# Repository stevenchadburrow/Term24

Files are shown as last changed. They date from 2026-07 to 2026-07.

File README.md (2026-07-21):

# Term24
VGA Terminal/Graphics Module using a PIC24<br>

This module is designed to output an 80x24 Terminal to a VGA display.  It accepts standard ANSI escape codes and includes customized escape codes for switching modes and changing internal memory.  It also has the capability of displaying 128x128 pixels at 128 colors, either double-buffered, layered, or with scrolling.  It has built in buttons to double as a gamepad.<br>

It can be accessed through four different protocols: UART, PS/2 Keyboard, SPI, or Parallel Input.  It can be used as a shield for the Arduino Uno, or it can be used with any homebrew computer and is easily plugged in to a breadboard.  It also has 'Tetra' as a built-in game!<br>

It uses the PIC24EP512GP202 microcontroller, running at 65 MIPS and containing 512KB of ROM and 48KB of RAM.  The only other IC on-board is the LM1117 voltage regulator.  All components are through-hole for ease of soldering.<br>

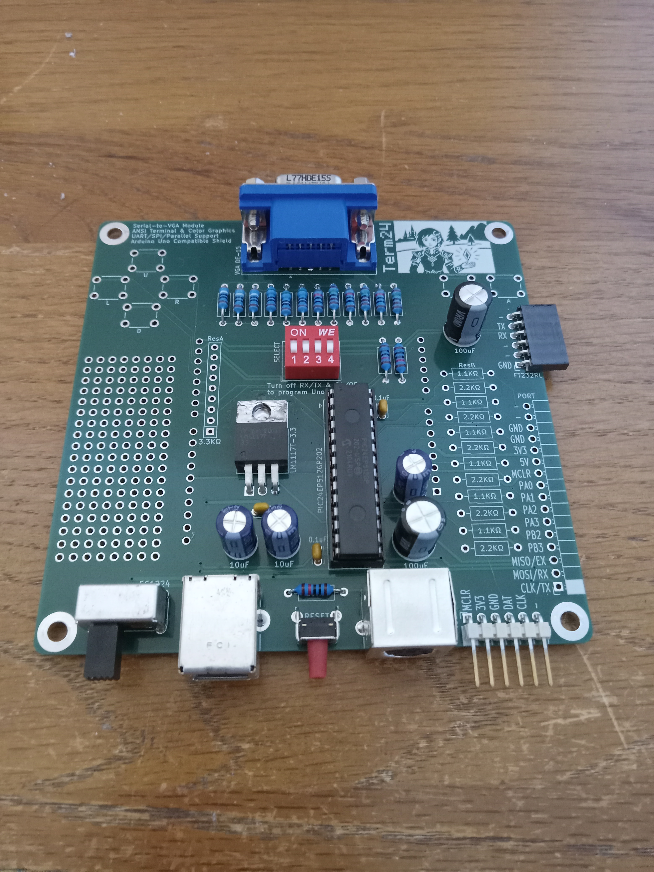
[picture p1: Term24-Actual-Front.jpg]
<br>
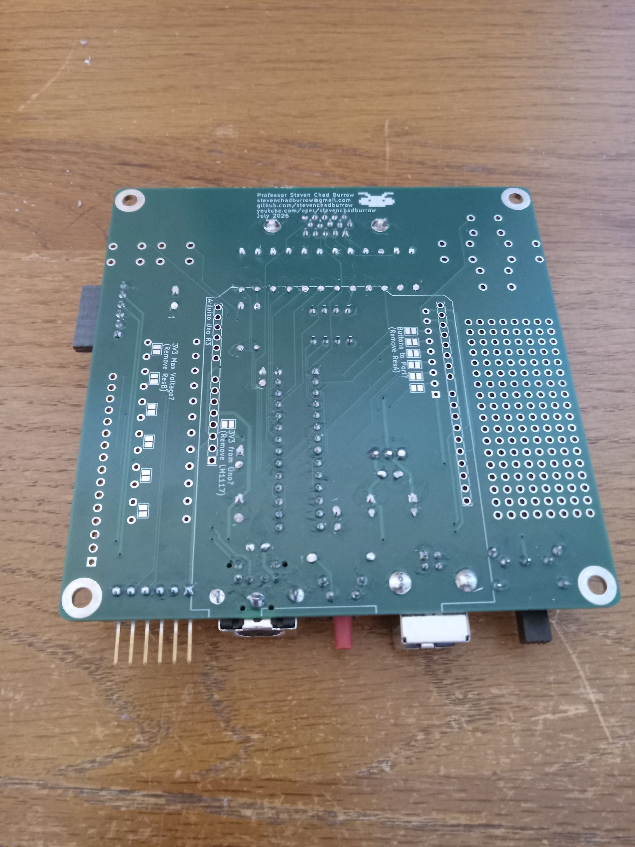
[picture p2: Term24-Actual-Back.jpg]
<br>
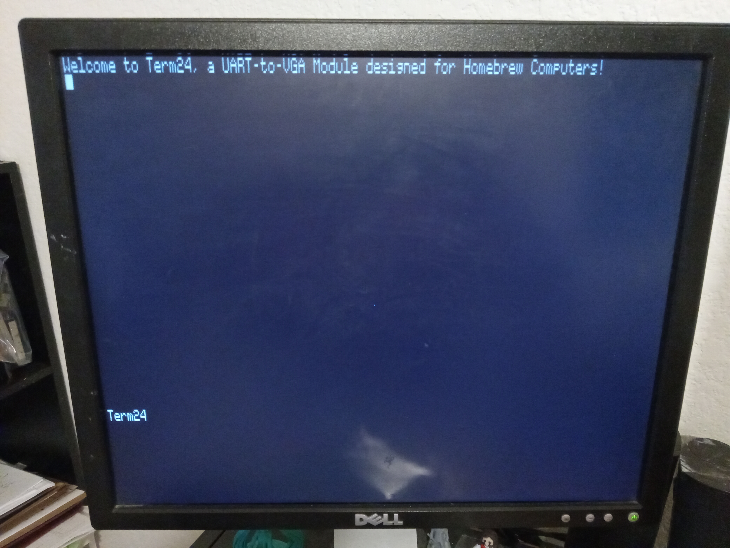
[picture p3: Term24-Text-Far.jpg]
<br>
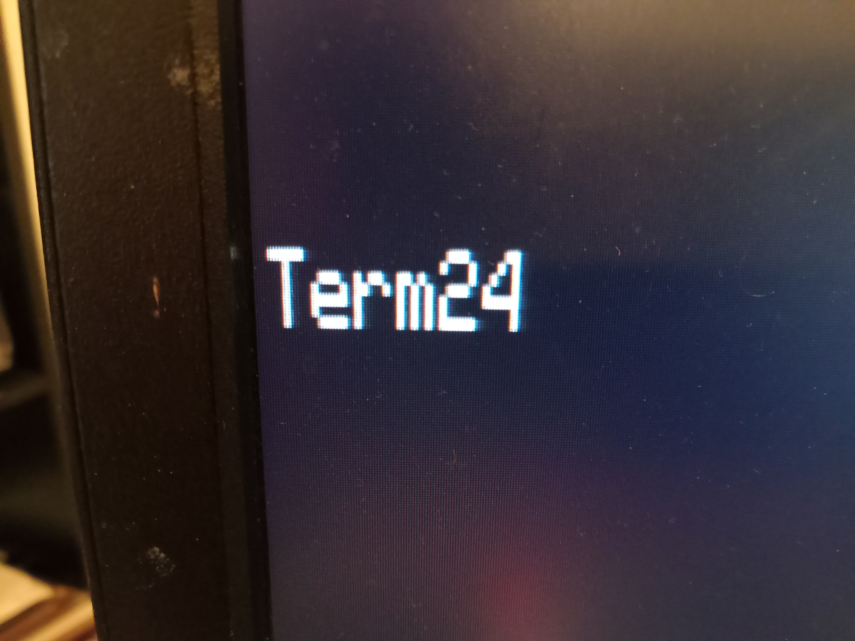
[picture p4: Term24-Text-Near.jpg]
<br>
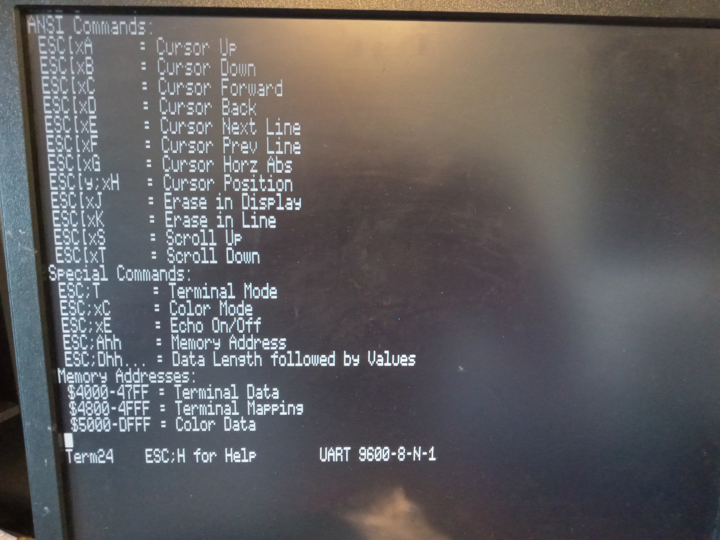
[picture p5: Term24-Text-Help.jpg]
<br>
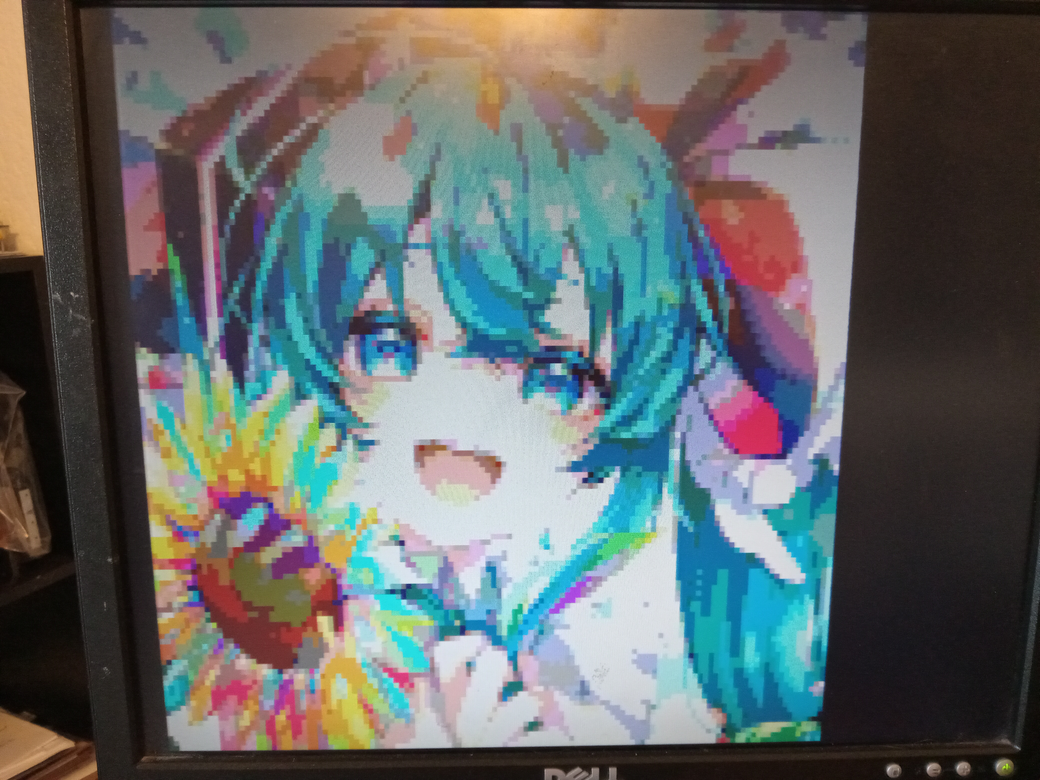
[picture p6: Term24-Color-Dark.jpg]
<br>
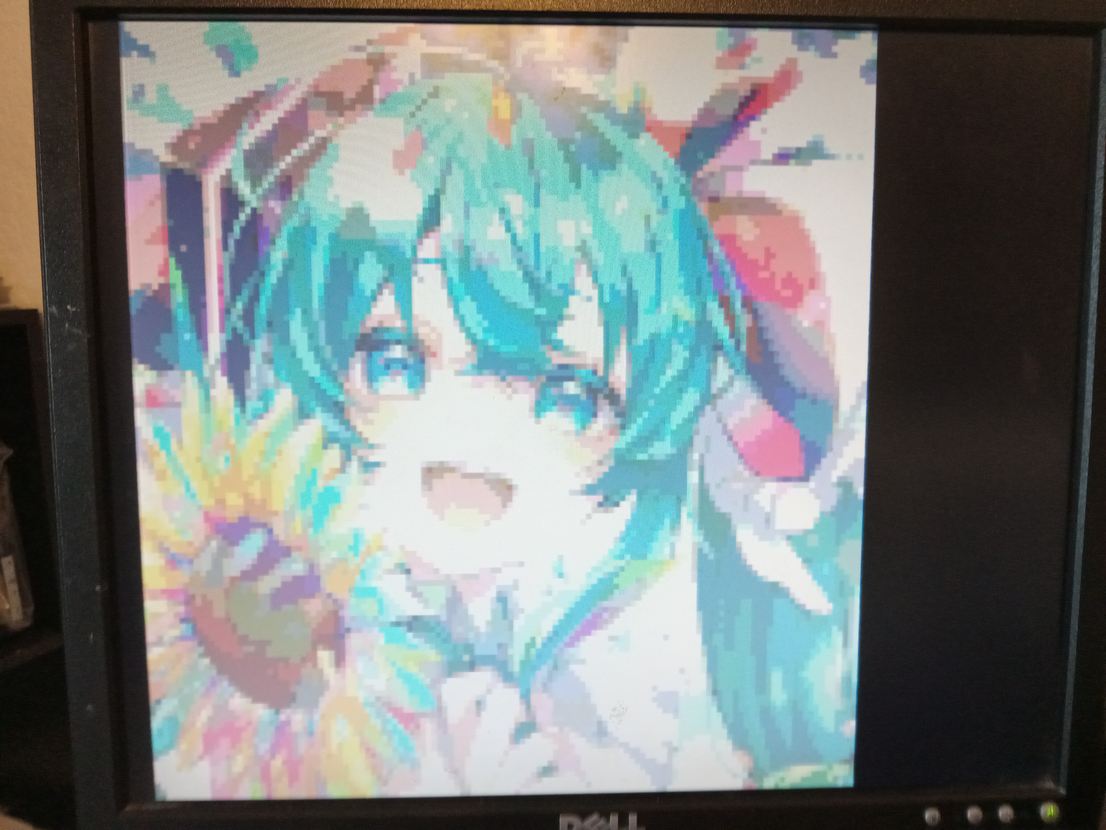
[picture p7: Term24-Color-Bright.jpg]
<br>
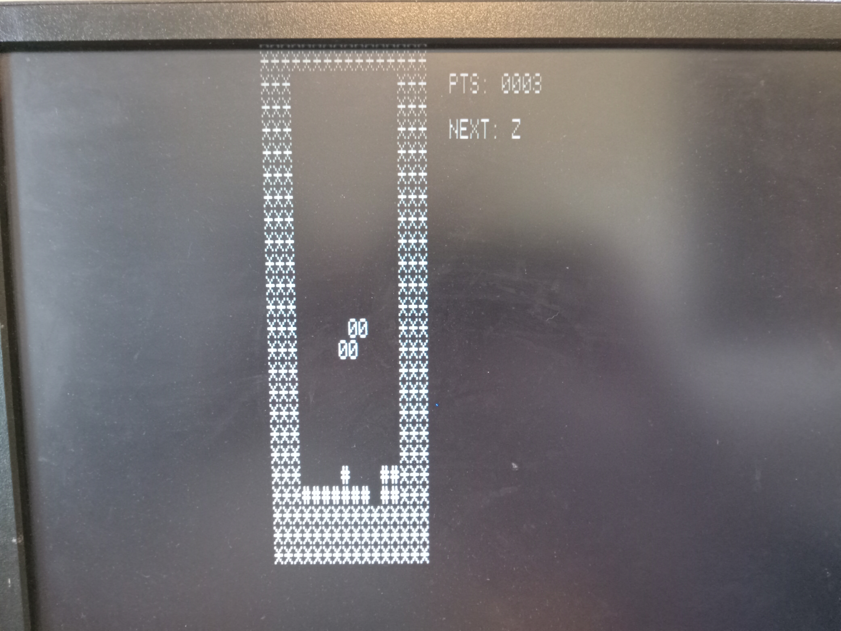
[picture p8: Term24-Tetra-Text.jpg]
<br>
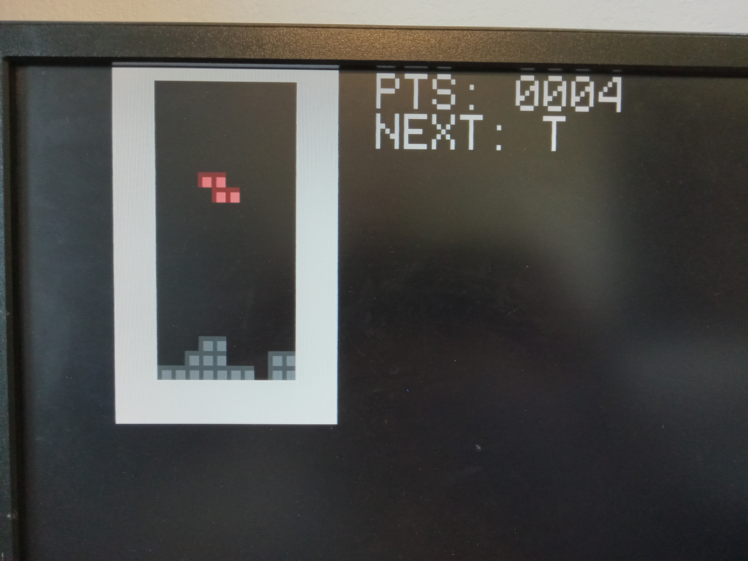
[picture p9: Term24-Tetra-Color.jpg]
<br>
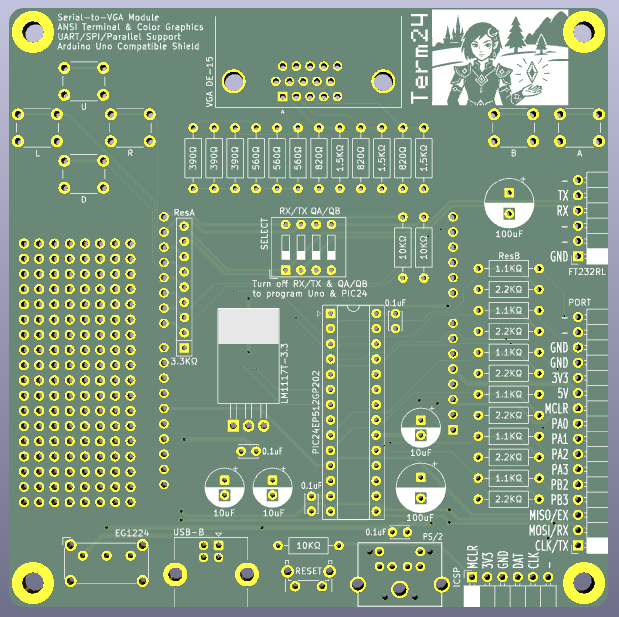
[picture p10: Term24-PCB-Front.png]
<br>
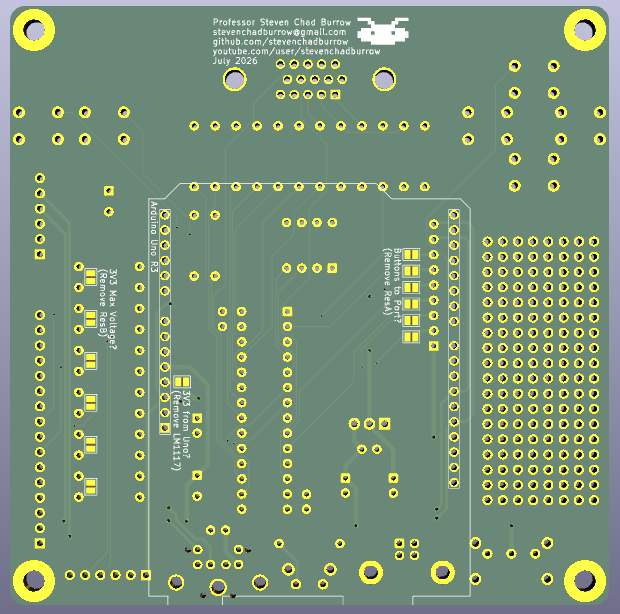
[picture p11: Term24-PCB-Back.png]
<br>

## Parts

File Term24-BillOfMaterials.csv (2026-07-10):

Quantity | Part ID | Description
1 | PIC24EP512GP202-I/SP | PIC24 Microcontroller
1 | 1-2199298-9 | DIP-28 Socket
1 | LM1117T-3.3/NOPB | LDO Voltage Regulator (3V3)
1 | L77HDE15SD1CH4FVGA | VGA Connector DE-15
1 | EG1224 | Power Switch
1 | 61729-1011RLF | USB-B Receptacle
1 | KMDGX-6S-BS | PS/2 Keyboard Connector
1 | SSQ-106-02-T-S-RA | 6-Pin Socket Horizontal
1 | TSW-116-25-L-S-RA | 6-Pin Header Horizontal
1 | TSW-116-25-L-S-RA | 16-Pin Header Horizontal
3 | 42375-1866 | 13-Pin Header Vertical (Breakway)
1 | PTS645VK83-2 LFS | Tactile Switch (Right Angle, 8.3mm)
6 | TS02-66-130-BK-160-SCR-D | Tactile Switch (6x6x13mm)
1 | 418117270904 | 4x DIP Switch
1 | 4609X-101-332LF | 8x Resistor Array 3.3K ohms
3 | ESK106M100AE3EA | 10uF Capacitor Electrolytic Radial
2 | UVR1H101MPD | 100uF Capacitor Electrolytic Radial
4 | K104K15X7RF5UL2 | 0.1uF Capacitor Ceramic MLCC
3 | MFR-25FRF52-10K | 10K ohm resistor 1/4W 1%
6 | MFR-25FRF52-1K1 | 1.1K ohm resistor 1/4W 1%
6 | MFR-25FRF52-2K2 | 2.2K ohm resistor 1/4W 1%
3 | MFR-25FTF52-390R | 390 ohm resistor 1/4W 1%
3 | MFR-25FTF52-560R | 560 ohm resistor 1/4W 1%
3 | MFR-25FBF52-820R | 820 ohm resistor 1/4W 1%
3 | MFR-25FTF52-1K5 | 1.5K ohm resistor 1/4W 1%

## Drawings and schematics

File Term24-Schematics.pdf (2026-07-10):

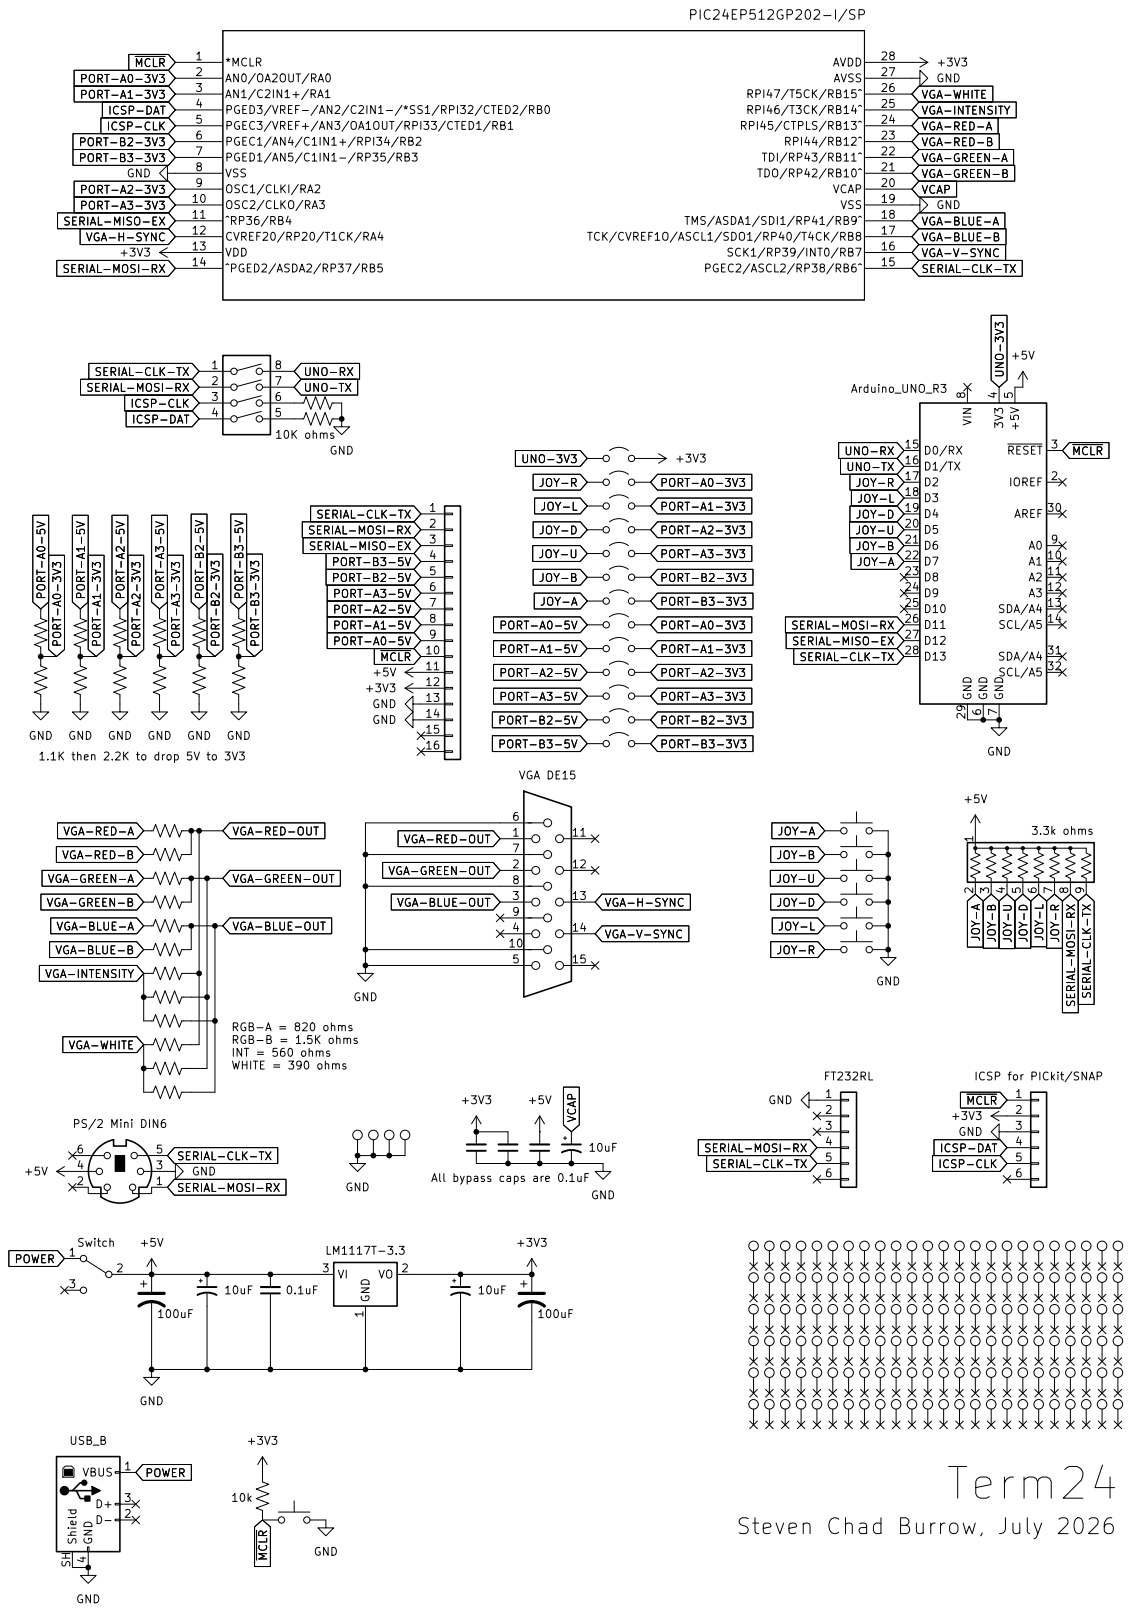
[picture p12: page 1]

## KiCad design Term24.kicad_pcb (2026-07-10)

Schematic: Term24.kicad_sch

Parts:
A1: Arduino_UNO_R3; Arduino_UNO_R3-Revised
C1, C6, C8: C_Polarized_Small_US; CP_Radial_D6.3mm_P2.50mm
C2, C3: C_Polarized_US; CP_Radial_D8.0mm_P3.50mm
C5, C19, C25, C26: C_Small; C_Disc_D3.0mm_W2.0mm_P2.50mm
J1: USB_B; USB_B_Lumberg_2411_02_Horizontal
J2: Conn_01x16; PinSocket_1x16_P2.54mm_Horizontal
J5: Mini-DIN-6; PS2_Din6
J11: VGA DE15; DSUB-15-HD_Socket_Horizontal_P2.29x2.54mm_EdgePinOffset8.35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
J14, J15: Conn_01x06; PinSocket_1x06_P2.54mm_Horizontal
JP1, JP2, JP3, JP4, JP5, JP6, JP7, JP8, JP9, JP10, JP11, JP12, JP13: Jumper_2_Open; SolderJumper-2_P1.3mm_Open_Pad1.0x1.5mm
R2, R9, R14, R16, R17, R18, R19, R20, R28, R29, R30, R31, R32, R33, R34, R35, R36, R37, R38, R39, R40, R41, R42, R43, R44, R45, R46: R_US; R_Axial_DIN0207_L6.3mm_D2.5mm_P10.16mm_Horizontal
RN1: R_Network08_US; R_Array_SIP9
SW3: SW_SPDT; SW_E-Switch_EG1224_SPDT_Angled
SW4, SW5, SW6, SW7, SW8, SW9: SW_Push; SW_PUSH_6mm_H7.3mm
SW10: SW_DIP_x04; SW_DIP_SPSTx04_Slide_9.78x12.34mm_W7.62mm_P2.54mm
SW11: SW_Push; SW_Tactile_SPST_Angled_PTS645Vx83-2LFS
TP1, TP6, TP7, TP8, TP9, TP10, TP11, TP12, TP13, TP14, TP15, TP16, TP17, TP18, TP19, TP20, TP21, TP22, TP23, TP24, TP25, TP26, TP27, TP28, TP29, TP30, TP31, TP32, TP33, TP34, TP35, TP36, TP37, TP38, TP39, TP40, TP41, TP42, TP43, TP44, TP45, TP46, TP47, TP48, TP49, TP50, TP51, TP52, TP53, TP54, TP55, TP56, TP57, TP58, TP59, TP60, TP61, TP62, TP63, TP64, TP65, TP66, TP67, TP68, TP69, TP70, TP71, TP72, TP73, TP74, TP75, TP76, TP77, TP78, TP79, TP80, TP81, TP82, TP83, TP84, TP85, TP86, TP87, TP88, TP89, TP90, TP91, TP92, TP93, TP94, TP95, TP96, TP97, TP98, TP99, TP100, TP101, TP102, TP103, TP104, TP105, TP106, TP107, TP108, TP109, TP110, TP111, TP112, TP113, TP114, TP115, TP116, TP117, TP118, TP119, TP120, TP121, TP122, TP123, TP124, TP125, TP126, TP127, TP128, TP129, TP130, TP131, TP132, TP133, TP134, TP135, TP136, TP137, TP138, TP139, TP140, TP141, TP142, TP143, TP144, TP145, TP146, TP147, TP148: TestPoint; PinHeader_1x01_P2.54mm_Vertical_TestPoint
TP2, TP3, TP4, TP5: TestPoint; ScrewHole-4-40
U1: PIC24EP512GP202-I/SP; DIP-28_W7.62mm_Socket
U5: LM1117T-3.3; TO-223-3-WithPad

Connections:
+3V3: C3.1, C6.1, C19.2, C25.2, J2.12, J14.2, JP13.2 (B), R2.2, U1.13 (VDD), U1.28 (AVDD), U5.2 (VO)
+5V: A1.5 (+5V), C2.1, C5.2, C8.1, C26.2, J2.11, J5.4, RN1.1 (common), SW3.2 (B), U5.3 (VI)
GND: A1.6 (GND), A1.7 (GND), A1.29 (GND), C1.2, C2.2, C3.2, C5.1, C6.2, C8.2, C19.1, C25.1, C26.1, J1.4 (GND), J1.SH (Shield), J2.13, J2.14, J5.3, J11.5, J11.6, J11.7, J11.8, J11.10, J14.3, J15.1, R33.1, R34.1, R36.2, R38.2, R40.2, R42.2, R44.2, R46.2, SW4.2, SW5.2, SW6.2, SW7.2, SW8.2, SW9.2, SW11.2, TP2.1 (1_1), TP3.1 (1_1), TP4.1 (1_1), TP5.1 (1_1), U1.8 (VSS), U1.19 (VSS), U1.27 (AVSS), U5.1 (GND)
ICSP-CLK: J14.5, SW10.3, U1.5 (PGEC3/VREF+/AN3/OA1OUT/RPI33/CTED1/RB1)
ICSP-DAT: J14.4, SW10.4, U1.4 (PGED3/VREF-/AN2/C2IN1-/*SS1/RPI32/CTED2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)
JOY-A: A1.22 (D7), JP12.1 (A), RN1.2 (R1), SW8.1
JOY-B: A1.21 (D6), JP11.1 (A), RN1.3 (R2), SW9.1
JOY-D: A1.19 (D4), JP9.1 (A), RN1.5 (R4), SW5.1
JOY-L: A1.18 (D3), JP8.1 (A), RN1.6 (R5), SW6.1
JOY-R: A1.17 (D2), JP7.1 (A), RN1.7 (R6), SW7.1
JOY-U: A1.20 (D5), JP10.1 (A), RN1.4 (R3), SW4.1
unnamed: R33.2, SW10.6
unnamed: R34.2, SW10.5
PORT-A0-3V3: JP1.2 (B), JP7.2 (B), R35.2, R36.1, U1.2 (AN0/OA2OUT/RA0)
PORT-A0-5V: J2.9, JP1.1 (A), R35.1
PORT-A1-3V3: JP2.2 (B), JP8.2 (B), R37.2, R38.1, U1.3 (AN1/C2IN1+/RA1)
PORT-A1-5V: J2.8, JP2.1 (A), R37.1
PORT-A2-3V3: JP3.2 (B), JP9.2 (B), R39.2, R40.1, U1.9 (OSC1/CLKI/RA2)
PORT-A2-5V: J2.7, JP3.1 (A), R39.1
PORT-A3-3V3: JP4.2 (B), JP10.2 (B), R41.2, R42.1, U1.10 (OSC2/CLKO/RA3)
PORT-A3-5V: J2.6, JP4.1 (A), R41.1
PORT-B2-3V3: JP5.2 (B), JP11.2 (B), R43.2, R44.1, U1.6 (PGEC1/AN4/C1IN1+/RPI34/RB2)
PORT-B2-5V: J2.5, JP5.1 (A), R43.1
PORT-B3-3V3: JP6.2 (B), JP12.2 (B), R45.2, R46.1, U1.7 (PGED1/AN5/C1IN1-/RP35/RB3)
PORT-B3-5V: J2.4, JP6.1 (A), R45.1
POWER: J1.1 (VBUS), SW3.1 (A)
SERIAL-CLK-TX: A1.28 (D13), J2.1, J5.5, J15.5, RN1.9 (R8), SW10.1, U1.15 (PGEC2/ASCL2/RP38/RB6^)
SERIAL-MISO-EX: A1.27 (D12), J2.3, U1.11 (^RP36/RB4)
SERIAL-MOSI-RX: A1.26 (D11), J2.2, J5.1, J15.4, RN1.8 (R7), SW10.2, U1.14 (^PGED2/ASDA2/RP37/RB5)
UNO-3V3: A1.4 (3V3), JP13.1 (A)
UNO-RX: A1.15 (D0/RX), SW10.8
UNO-TX: A1.16 (D1/TX), SW10.7
VCAP: C1.1, U1.20 (VCAP)
VGA-BLUE-A: R19.2, U1.18 (TMS/ASDA1/SDI1/RP41/RB9^)
VGA-BLUE-B: R20.2, U1.17 (TCK/CVREF1O/ASCL1/SDO1/RP40/T4CK/RB8)
VGA-BLUE-OUT: J11.3, R19.1, R20.1, R29.1, R32.1
VGA-GREEN-A: R16.2, U1.22 (TDI/RP43/RB11^)
VGA-GREEN-B: R17.2, U1.21 (TDO/RP42/RB10^)
VGA-GREEN-OUT: J11.2, R16.1, R17.1, R28.1, R31.1
VGA-H-SYNC: J11.13, U1.12 (CVREF20/RP20/T1CK/RA4)
VGA-INTENSITY: R18.2, R28.2, R29.2, U1.25 (RPI46/T3CK/RB14^)
VGA-RED-A: R9.2, U1.24 (RPI45/CTPLS/RB13^)
VGA-RED-B: R14.2, U1.23 (RPI44/RB12^)
VGA-RED-OUT: J11.1, R9.1, R14.1, R18.1, R30.1
VGA-V-SYNC: J11.14, U1.16 (SCK1/RP39/INT0/RB7)
VGA-WHITE: R30.2, R31.2, R32.2, U1.26 (RPI47/T5CK/RB15^)
~MCLR: A1.3 (~RESET), J2.10, J14.1, R2.1, SW11.1, U1.1 (*MCLR)

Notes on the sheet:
1.1K then 2.2K to drop 5V to 3V3
Steven Chad Burrow, July 2026
10K ohms
https://falstad.com/circuit/circuitjs.html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…
RGB-A = 820 ohms RGB-B = 1.5K ohms INT = 560 ohms WHITE = 390 ohms
Term24
All bypass caps are 0.1uF

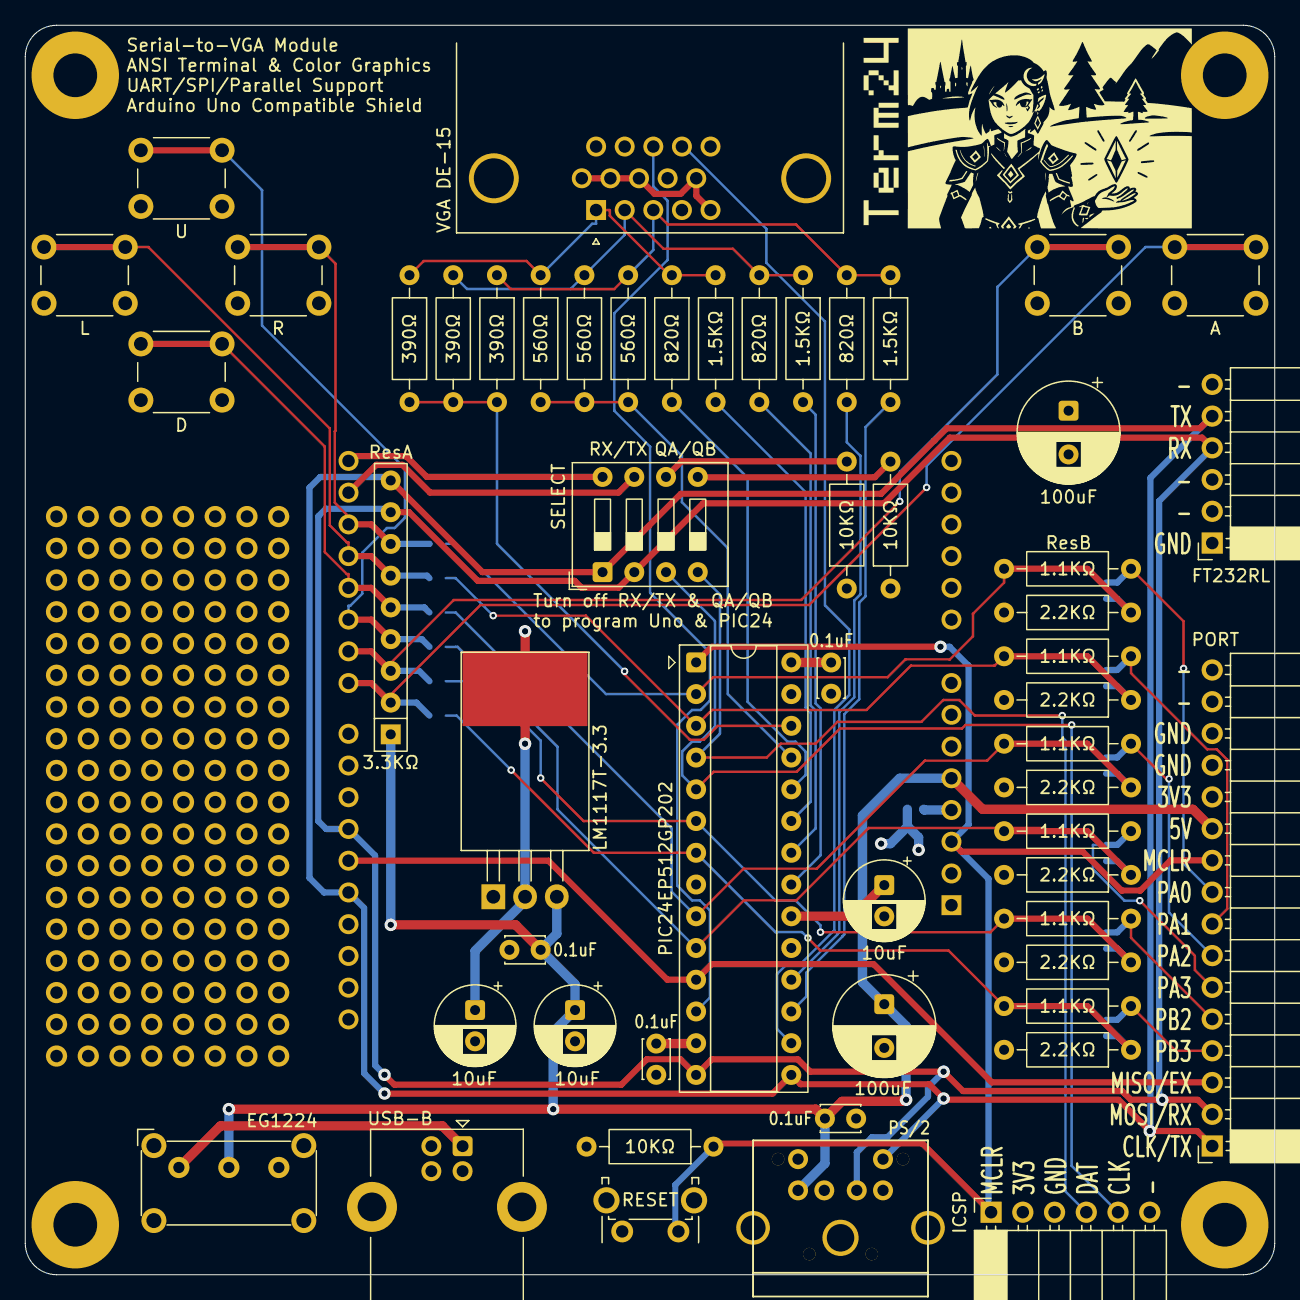
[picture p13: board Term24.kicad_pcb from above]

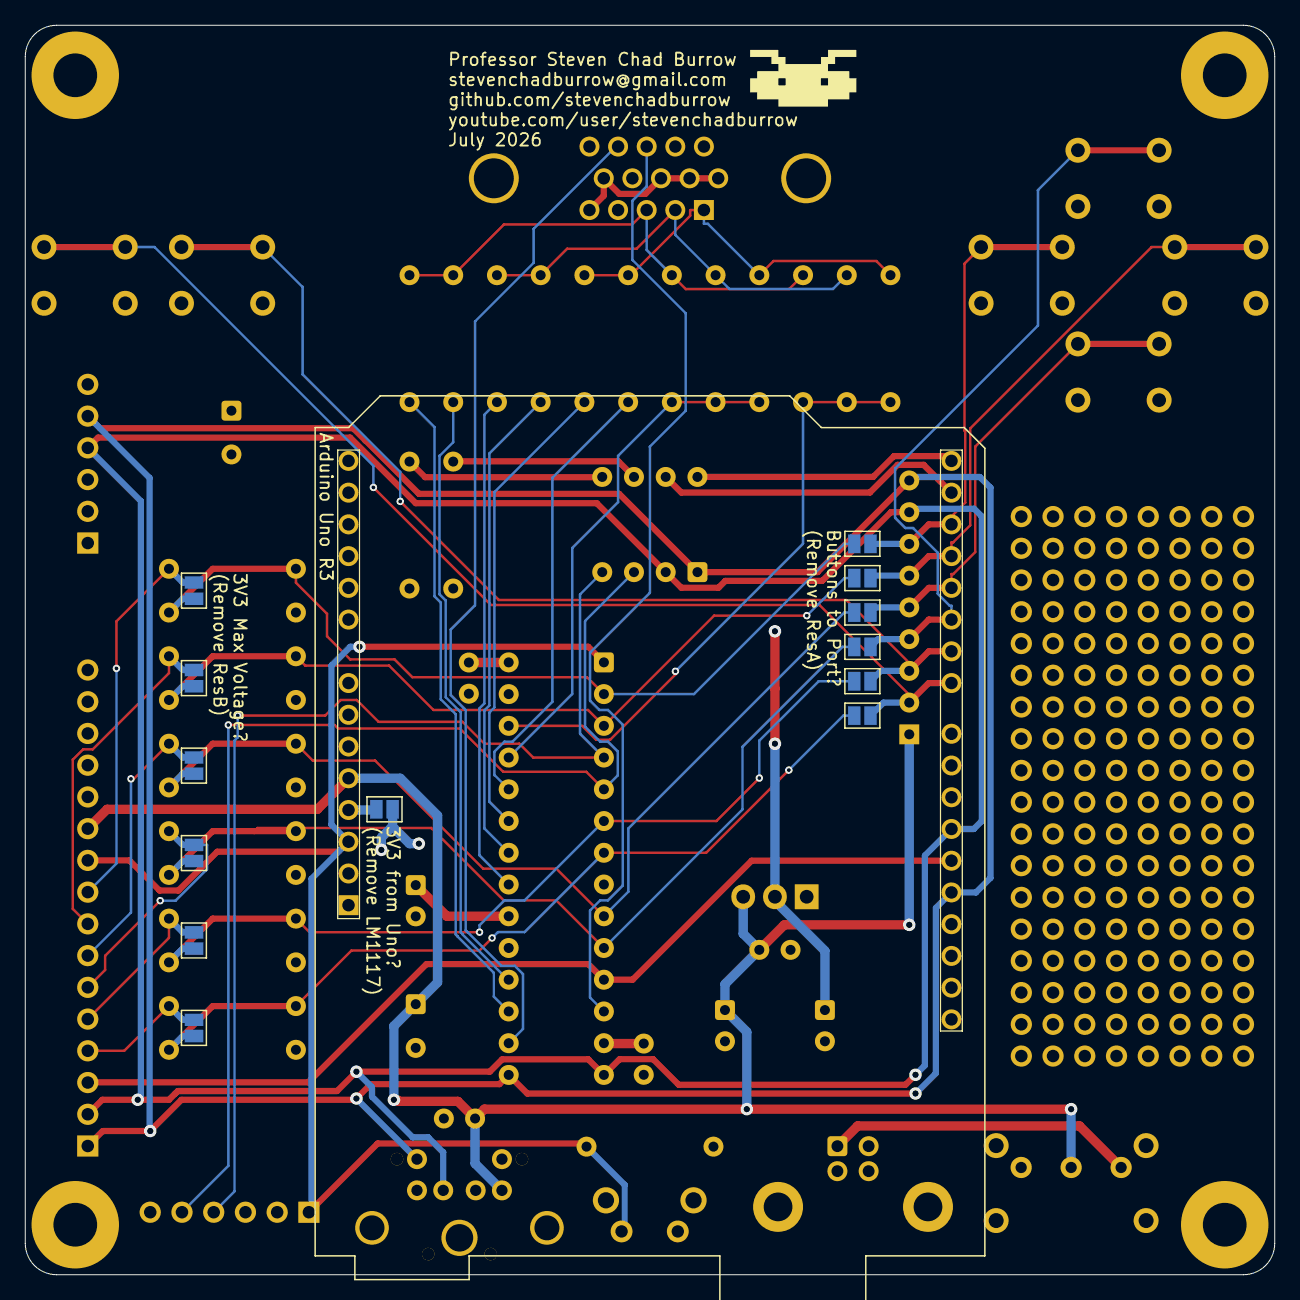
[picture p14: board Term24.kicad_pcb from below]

Board: 4 copper layers, 100.0 x 100.0 mm, 219 parts (15 on the bottom side), 47 nets.

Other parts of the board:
G100: LOGO; Title
G101: LOGO; Logo
G102: LOGO; Girl

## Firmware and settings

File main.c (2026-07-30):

// Term24 - VGA Terminal Module using the PIC24.
// Supports: UART, SPI, I2C, and PS/2 Keyboard.
// Includes color mode for 128x128 resolution at 128-colors, with scrolling or layers.

/*
XGA Signal 1024 x 768 @ 60 Hz timing

General timing
Screen refresh rate	60 Hz
Vertical refresh	48.363095238095 kHz
Pixel freq.	65.0 MHz
Horizontal timing (line)
Polarity of horizontal sync pulse is negative.

Scanline part	Pixels	Time [µs]
Visible area	1024	15.753846153846
Front porch	24	0.36923076923077
Sync pulse	136	2.0923076923077
Back porch	160	2.4615384615385
Whole line	1344	20.676923076923
Vertical timing (frame)
Polarity of vertical sync pulse is negative.

Frame part	Lines	Time [ms]
Visible area	768	15.879876923077
Front porch	3	0.062030769230769
Sync pulse	6	0.12406153846154
Back porch	29	0.59963076923077
Whole frame	806	16.6656
*/

// PIC24EP512GP202 Configuration Bit Settings

// 'C' source line config statements

// FICD
#pragma config ICS = PGD3               // ICD Communication Channel Select bits (Communicate on PGEC3 and PGED3)
#pragma config JTAGEN = OFF             // JTAG Enable bit (JTAG is disabled)

// FPOR
#pragma config ALTI2C1 = OFF            // Alternate I2C1 pins (I2C1 mapped to SDA1/SCL1 pins)
#pragma config ALTI2C2 = ON             // Alternate I2C2 pins (I2C2 mapped to ASDA2/ASCL2 pins)
#pragma config WDTWIN = WIN25           // Watchdog Window Select bits (WDT Window is 25% of WDT period)

// FWDT
#pragma config WDTPOST = PS32768        // Watchdog Timer Postscaler bits (1:32,768)
#pragma config WDTPRE = PR128           // Watchdog Timer Prescaler bit (1:128)
#pragma config PLLKEN = OFF             // PLL Lock Enable bit (Clock switch will not wait for the PLL lock signal.)
#pragma config WINDIS = OFF             // Watchdog Timer Window Enable bit (Watchdog Timer in Non-Window mode)
#pragma config FWDTEN = OFF             // Watchdog Timer Enable bit (Watchdog timer enabled/disabled by user software)

// FOSC
#pragma config POSCMD = NONE            // Primary Oscillator Mode Select bits (Primary Oscillator disabled)
#pragma config OSCIOFNC = ON            // OSC2 Pin Function bit (OSC2 is general purpose digital I/O pin)
#pragma config IOL1WAY = OFF            // Peripheral pin select configuration (Allow multiple reconfigurations)
#pragma config FCKSM = CSECMD           // Clock Switching Mode bits (Clock switching is enabled,Fail-safe Clock Monitor is disabled)

// FOSCSEL
#pragma config FNOSC = FRCPLL           // Oscillator Source Selection (Fast RC Oscillator with divide-by-N with PLL module (FRCPLL))
#pragma config IESO = OFF               // Two-speed Oscillator Start-up Enable bit (Start up with user-selected oscillator source)

// FGS
#pragma config GWRP = OFF               // General Segment Write-Protect bit (General Segment may be written)
#pragma config GCP = OFF                // General Segment Code-Protect bit (General Segment Code protect is Disabled)

// #pragma config statements should precede project file includes.
// Use project enums instead of #define for ON and OFF.

#include <xc.h>

#include <p24Exxxx.h>

// unused memory here
volatile unsigned char __attribute__((address(0x2800))) term_game_field[512]; // only uses 200 bytes plus borders
volatile unsigned char __attribute__((address(0x2A00))) term_pixels[80];
volatile unsigned char __attribute__((address(0x2A50))) term_buffer[80];
volatile unsigned int __attribute__((address(0x2AA0))) term_scanline;
volatile unsigned int __attribute__((address(0x2AA2))) term_location;
volatile unsigned int __attribute__((address(0x2AA4))) term_counter;
volatile unsigned int __attribute__((address(0x2AA6))) term_stretch;
volatile unsigned int __attribute__((address(0x2AA8))) term_scroll;
volatile unsigned int __attribute__((address(0x2AAA))) term_orientation;
volatile unsigned int __attribute__((address(0x2AAC))) term_cursor; 
volatile unsigned int __attribute__((address(0x2AAE))) term_mode; // 0 = text, 1 = color
volatile unsigned int __attribute__((address(0x2AB0))) term_bottom_text; // 0x0780 by default
volatile unsigned int __attribute__((address(0x2AB2))) term_bottom_color; // 0x02FF by default
volatile unsigned int __attribute__((address(0x2AB4))) term_parallel;
volatile unsigned int __attribute__((address(0x2AB6))) term_last_channel;
volatile unsigned int __attribute__((address(0x2AB8))) term_last_address;
volatile unsigned int __attribute__((address(0x2ABA))) term_ps2_release;
volatile unsigned int __attribute__((address(0x2ABC))) term_ps2_extended;
volatile unsigned int __attribute__((address(0x2ABE))) term_ps2_shift;
volatile unsigned int __attribute__((address(0x2AC0))) term_ps2_capslock;
volatile unsigned int __attribute__((address(0x2AC2))) term_signal_synced;
volatile unsigned int __attribute__((address(0x2AC4))) term_sequence;
volatile unsigned int __attribute__((address(0x2AC6))) term_command;
volatile unsigned int __attribute__((address(0x2AC8))) term_print;
volatile unsigned int __attribute__((address(0x2ACA))) term_dma_address;
volatile unsigned int __attribute__((address(0x2ACC))) term_dma_data; 
volatile unsigned int __attribute__((address(0x2ACE))) term_position;
volatile unsigned char __attribute__((address(0x2AD0))) term_keycode[8];
volatile unsigned int __attribute__((address(0x2AD8))) term_setting_legacy;
volatile unsigned int __attribute__((address(0x2ADA))) term_setting_echo;
volatile unsigned int __attribute__((address(0x2ADC))) term_game_piece_current;
volatile unsigned int __attribute__((address(0x2ADE))) term_game_piece_next;
volatile signed int __attribute__((address(0x2AE0))) term_game_piece_x;
volatile signed int __attribute__((address(0x2AE2))) term_game_piece_y;
volatile signed int __attribute__((address(0x2AE4))) term_game_piece_rot;
volatile unsigned int __attribute__((address(0x2AE6))) term_game_button_current;
volatile unsigned int __attribute__((address(0x2AE8))) term_game_button_previous;
volatile unsigned int __attribute__((address(0x2AEA))) term_game_button_held;
volatile unsigned int __attribute__((address(0x2AEC))) term_game_delay_low;
volatile unsigned int __attribute__((address(0x2AEE))) term_game_delay_high;
volatile unsigned int __attribute__((address(0x2AF0))) term_game_counter_low;
volatile unsigned int __attribute__((address(0x2AF2))) term_game_counter_high;
volatile unsigned int __attribute__((address(0x2AF4))) term_game_points;
volatile unsigned int __attribute__((address(0x2AF6))) term_game_tally;
volatile unsigned int __attribute__((address(0x2AF8))) term_game_seed;
volatile unsigned int __attribute__((address(0x2AFA))) term_game_bit;
volatile unsigned int __attribute__((address(0x2AFC))) term_unused[2]; // unused memory
volatile unsigned char __attribute__((address(0x2B00))) term_ps2_conversion[256];
volatile unsigned int __attribute__((address(0x2C00))) term_array[256];
// unused memory here (generally used by heap, 512 bytes)
volatile unsigned char __attribute__((address(0x3000))) term_map[2048];
volatile unsigned char __attribute__((address(0x3800))) term_memory[18432];
//volatile unsigned char __attribute__((address(0x5000))) term_color[12288]; // integrated with term_memory[] now
volatile __eds__ unsigned char __attribute__((address(0x8000), eds)) term_color_eds[20480];

unsigned char __attribute__((section("usercode"))) term_read(unsigned int a)
{
	if (a >= 0x3000 && a < 0x3800)
	{
		return term_map[a-0x3000];
	}
	else if (a >= 0x3800 && a < 0x8000)
	{
		return term_memory[a-0x3800];
	}
	//else if (a >= 0x5000 && a < 0x8000)
	//{
	//	return term_color[a-0x5000];
	//}
	else if (a >= 0x8000 && a < 0xD000)
	{
		return term_color_eds[a-0x8000];
	}

	return 0x00;
};

void __attribute__((section("usercode"))) term_write(unsigned int a, unsigned char d)
{
	if (a >= 0x3000 && a < 0x3800)
	{
		term_map[a-0x3000] = d;
	}
	else if (a >= 0x3800 && a < 0x8000)
	{
		term_memory[a-0x3800] = d;
	}
	//else if (a >= 0x5000 && a < 0x8000)
	//{
	//	term_color[a-0x5000] = d;
	//}
	else if (a >= 0x8000 && a < 0xD000)
	{
		term_color_eds[a-0x8000] = d;
	}
};

extern void __attribute__((section("usercode"))) TermScanline(void);

// interrupt latency is 10 cycles
// for some reason, having auto_psv instead of no_auto_psv makes this work?!
void __attribute__((interrupt, auto_psv, address(0x010600))) _T1Interrupt(void)
{
	// C always includes:
	// lnk #0
  
	TermScanline();
	
	// C always includes:
	// ulnk
	// retfie
};

// text character mapping, 8-bytes per character
const __prog__ unsigned char __attribute__((space(prog), section("usercode"))) text_map[768] = {
	0x00, 0x00, 0x00, 0x00, 0x00, 0x00, 0x00, 0x00, 
	0x20, 0x20, 0x20, 0x20, 0x20, 0x00, 0x20, 0x00, 
	0x50, 0x50, 0x00, 0x00, 0x00, 0x00, 0x00, 0x00, 
	0x50, 0x50, 0xF8, 0x50, 0xF8, 0x50, 0x50, 0x00, 
	0x70, 0xA8, 0xA0, 0x70, 0x28, 0xA8, 0x70, 0x00, 
	0x88, 0x08, 0x10, 0x20, 0x40, 0x80, 0x88, 0x00, 
	0x60, 0x90, 0x90, 0x60, 0xA8, 0x90, 0x68, 0x00, 
	0x20, 0x20, 0x00, 0x00, 0x00, 0x00, 0x00, 0x00, 
	0x10, 0x20, 0x20, 0x20, 0x20, 0x20, 0x10, 0x00, 
	0x40, 0x20, 0x20, 0x20, 0x20, 0x20, 0x40, 0x00, 
	0x88, 0x50, 0x20, 0xF8, 0x20, 0x50, 0x88, 0x00, 
	0x00, 0x00, 0x20, 0x70, 0x20, 0x00, 0x00, 0x00, 
	0x00, 0x00, 0x00, 0x00, 0x00, 0x20, 0x40, 0x00, 
	0x00, 0x00, 0x00, 0x70, 0x00, 0x00, 0x00, 0x00, 
	0x00, 0x00, 0x00, 0x00, 0x00, 0x00, 0x20, 0x00, 
	0x08, 0x08, 0x10, 0x20, 0x40, 0x80, 0x80, 0x00, 
	0x70, 0x88, 0x98, 0xA8, 0xC8, 0x88, 0x70, 0x00, 
	0x20, 0x60, 0xA0, 0x20, 0x20, 0x20, 0xF8, 0x00, 
	0x70, 0x88, 0x08, 0x70, 0x80, 0x80, 0xF8, 0x00, 
	0x70, 0x88, 0x08, 0x70, 0x08, 0x88, 0x70, 0x00, 
	0x18, 0x28, 0x48, 0x88, 0xF8, 0x08, 0x08, 0x00, 
	0xF8, 0x80, 0x80, 0xF0, 0x08, 0x88, 0x70, 0x00, 
	0x70, 0x88, 0x80, 0xF0, 0x88, 0x88, 0x70, 0x00, 
	0xF8, 0x08, 0x10, 0x20, 0x20, 0x20, 0x20, 0x00, 
	0x70, 0x88, 0x88, 0x70, 0x88, 0x88, 0x70, 0x00, 
	0x70, 0x88, 0x88, 0x78, 0x08, 0x88, 0x70, 0x00, 
	0x00, 0x00, 0x20, 0x00, 0x00, 0x00, 0x20, 0x00, 
	0x00, 0x00, 0x20, 0x00, 0x00, 0x20, 0x40, 0x00, 
	0x00, 0x00, 0x20, 0x40, 0x20, 0x00, 0x00, 0x00, 
	0x00, 0x00, 0x70, 0x00, 0x70, 0x00, 0x00, 0x00, 
	0x00, 0x00, 0x20, 0x10, 0x20, 0x00, 0x00, 0x00, 
	0x70, 0x88, 0x08, 0x10, 0x20, 0x00, 0x20, 0x00, 
	0x70, 0x88, 0xA8, 0xA8, 0xB8, 0x80, 0xF8, 0x00, 
	0x20, 0x50, 0x88, 0xF8, 0x88, 0x88, 0x88, 0x00, 
	0xF0, 0x88, 0x88, 0xF0, 0x88, 0x88, 0xF0, 0x00, 
	0x70, 0x88, 0x80, 0x80, 0x80, 0x88, 0x70, 0x00, 
	0xF0, 0x88, 0x88, 0x88, 0x88, 0x88, 0xF0, 0x00, 
	0xF8, 0x80, 0x80, 0xF0, 0x80, 0x80, 0xF8, 0x00, 
	0xF8, 0x80, 0x80, 0xF0, 0x80, 0x80, 0x80, 0x00, 
	0x70, 0x88, 0x80, 0xB8, 0x88, 0x88, 0x78, 0x00, 
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
	0xF8, 0xF8, 0xF8, 0xF8, 0xF8, 0xF8, 0xF8, 0x00, // 0x7F, DEL, used for cursor?
};

// modified by-hand some
const __prog__ unsigned char __attribute__((space(prog), section("usercode"))) text_conversion[256] = {
	// regular
	0x00, 0x00, 0x00, 0x00, 0x00, 0x00, 0x00, 0x00, // 0x
	0x00, 0x00, 0x00, 0x00, 0x00, 0x09, 0x60, 0x00, 
	0x00, 0x00, 0x00, 0x00, 0x00, 0x71, 0x31, 0x00, // 1x
	0x00, 0x00, 0x7A, 0x73, 0x61, 0x77, 0x32, 0x00,
	0x00, 0x63, 0x78, 0x64, 0x65, 0x34, 0x33, 0x00, // 2x
	0x00, 0x20, 0x76, 0x66, 0x74, 0x72, 0x35, 0x00,
	0x00, 0x6E, 0x62, 0x68, 0x67, 0x79, 0x36, 0x00, // 3x
	0x00, 0x00, 0x6D, 0x6A, 0x75, 0x37, 0x38, 0x00,
	0x00, 0x2C, 0x6B, 0x69, 0x6F, 0x30, 0x39, 0x00, // 4x 
	0x00, 0x2E, 0x2F, 0x6C, 0x3B, 0x70, 0x2D, 0x00, 
	0x00, 0x00, 0x27, 0x00, 0x5B, 0x3D, 0x00, 0x00, // 5x
	0x00, 0x00, 0x0D, 0x5D, 0x00, 0x5C, 0x00, 0x00, 
	0x00, 0x00, 0x00, 0x00, 0x00, 0x00, 0x7F, 0x00, // 6x
	0x00, 0x31, 0x00, 0x34, 0x37, 0x00, 0x00, 0x00, 
	0x30, 0x2E, 0x32, 0x35, 0x36, 0x38, 0x1B, 0x00, // 7x
	0x00, 0x2B, 0x33, 0x2D, 0x2A, 0x39, 0x00, 0x00, 
	// term_ps2_shifted
	0x00, 0x00, 0x00, 0x00, 0x00, 0x00, 0x00, 0x00, // 8x
	0x00, 0x00, 0x00, 0x00, 0x00, 0x09, 0x7E, 0x00, 
	0x00, 0x00, 0x00, 0x00, 0x00, 0x51, 0x21, 0x00, // 9x
	0x00, 0x00, 0x5A, 0x53, 0x41, 0x57, 0x40, 0x00, 
	0x00, 0x43, 0x58, 0x44, 0x45, 0x24, 0x23, 0x00, // Ax
	0x00, 0x00, 0x56, 0x46, 0x54, 0x52, 0x25, 0x00, 
	0x00, 0x4E, 0x42, 0x48, 0x47, 0x2B, 0x5E, 0x00, // Bx
	0x00, 0x00, 0x4D, 0x4A, 0x55, 0x26, 0x2A, 0x00, 
	0x00, 0x3C, 0x4B, 0x49, 0x4F, 0x29, 0x28, 0x00, // Cx
	0x00, 0x3E, 0x3F, 0x4C, 0x3A, 0x50, 0x5F, 0x00, 
	0x00, 0x00, 0x22, 0x00, 0x7B, 0x2B, 0x00, 0x00, // Dx
	0x00, 0x00, 0x0D, 0x7D, 0x00, 0x7C, 0x00, 0x00, 
	0x00, 0x00, 0x00, 0x00, 0x00, 0x00, 0x7F, 0x00, // Ex
	0x00, 0x17, 0x00, 0x14, 0x19, 0x00, 0x00, 0x00, 
	0x00, 0x00, 0x12, 0x00, 0x13, 0x11, 0x1B, 0x00, // Fx
	0x00, 0x00, 0x00, 0x00, 0x00, 0x00, 0x00, 0x00, 
};

const __prog__ char __attribute__((space(prog), section("usercode"))) text_menu_0[32] = {
	"Term24    ESC;H for Help      \\" };
const __prog__ char __attribute__((space(prog), section("usercode"))) text_menu_1[48] = {
	"UART 9600-8-N-1                                \\" };
const __prog__ char __attribute__((space(prog), section("usercode"))) text_menu_2[48] = {
	"PS/2 Press = or send $55 to sync ?\??\?-8-O-1  \\" };
const __prog__ char __attribute__((space(prog), section("usercode"))) text_menu_3[48] = {
	"SPI (3-WIRE) Send 2 bytes then pause to sync   \\" };
const __prog__ char __attribute__((space(prog), section("usercode"))) text_menu_4[48] = {
	"PARALLEL                                       \\" };

const __prog__ char __attribute__((space(prog), section("usercode"))) text_help_0[80] = {
	"Commands:                        ESC;xT     = Text Mode                         " };
const __prog__ char __attribute__((space(prog), section("usercode"))) text_help_1[80] = {
	" ESC[xA   = Cursor Up            ESC;xC     = Color Mode                        " };
const __prog__ char __attribute__((space(prog), section("usercode"))) text_help_2[80] = {
	" ESC[xB   = Cursor Down          ESC;xL     = Legacy On/Off                     " };
const __prog__ char __attribute__((space(prog), section("usercode"))) text_help_3[80] = {
	" ESC[xC   = Cursor Forward       ESC;xE     = Echo On/Off                       " };
const __prog__ char __attribute__((space(prog), section("usercode"))) text_help_4[80] = {
	" ESC[xD   = Cursor Back          ESC;xS     = Scan from Cursor                  " };
const __prog__ char __attribute__((space(prog), section("usercode"))) text_help_5[80] = {
	" ESC[xE   = Cursor Next Line     ESC;hhA    = Mem Address                       " };
const __prog__ char __attribute__((space(prog), section("usercode"))) text_help_6[80] = {
	" ESC[xF   = Cursor Prev Line     ESC;hhR    = Read Memory                       " };
const __prog__ char __attribute__((space(prog), section("usercode"))) text_help_7[80] = {
	" ESC[xG   = Cursor Horz Abs      ESC;hhW... = Write Memory                      " };
const __prog__ char __attribute__((space(prog), section("usercode"))) text_help_8[80] = {
	" ESC[y;xH = Cursor Position     Memory Addresses:                               " };
const __prog__ char __attribute__((space(prog), section("usercode"))) text_help_9[80] = {
	" ESC[xJ   = Erase in Display     $3000-37FF = Text Mapping                      " };
const __prog__ char __attribute__((space(prog), section("usercode"))) text_help_10[80] = {
	" ESC[xK   = Erase in Line        $3800-4FFF = Text Only Data                    " };
const __prog__ char __attribute__((space(prog), section("usercode"))) text_help_11[80] = {
	" ESC[xS   = Scroll Up            $5000-7FFF = Text/Color Data                   " };
const __prog__ char __attribute__((space(prog), section("usercode"))) text_help_12[80] = {
	" ESC[xT   = Scroll Down          $8000-DFFF = EDS Color Data                    " };
const __prog__ char __attribute__((space(prog), section("usercode"))) text_help_13[80] = {
	"Firmware Update on Reset if PA0-PA3 grounded, send Intel HEX at 9600-8-N-1.     " };


void __attribute__((section("usercode"))) color_character(int x, int y, unsigned char c)
{
	if (c < 0x20 || c >= 0x80) return;

	unsigned char v;

	for (int i=0; i<8; i++)
	{
		v = text_map[(c - 0x20) * 8 + i];

		for (int j=0; j<6; j++)
		{
			if ((v & 0x80) == 0x80) term_memory[(y+i)*128+(x+j)+0x1800] = 0x7F;
			else term_memory[(y+i)*128+(x+j)+0x1800] = 0x00;

			v <<= 1;
		}
	}
};

void __attribute__((section("usercode"))) text_character(int x, int y, unsigned char c)
{
	term_memory[y*80+x] = (unsigned int)c;
};

void __attribute__((section("usercode"))) text_string(int x, int y, const __prog__ char *s)
{
	for (int i=0; i<80; i++)
	{
		if (s[i] == '\\') return;

		text_character(x+i, y, s[i]);
	}
};

char __attribute__((section("usercode"))) text_high_nibble(unsigned char c)
{
	if ((c & 0xF0) >= 0xA0)
	{
		return ((c & 0xF0) >> 4) - 10 + 'A';
	}
	else
	{
		return ((c & 0xF0) >> 4) + '0';
	}
};

char __attribute__((section("usercode"))) text_low_nibble(unsigned char c)
{
	if ((c & 0x0F) >= 0x0A)
	{
		return (c & 0x0F) - 10 + 'A';
	}
	else
	{
		return (c & 0x0F) + '0';
	}
};

void __attribute__((interrupt, auto_psv, address(0x010100))) _U1RXInterrupt(void)
{
	IFS0bits.U1RXIF = 0; // Clear RX Interrupt flag
};

void __attribute__((interrupt, auto_psv, address(0x010200))) _U1TXInterrupt(void)
{
	IFS0bits.U1TXIF = 0; // Clear TX Interrupt flag
};

void __attribute__((interrupt, auto_psv, address(0x010300))) _SPI2Interrupt(void)
{
	IFS2bits.SPI2IF = 0; // clear flag
}

void __attribute__((interrupt, auto_psv, address(0x010400))) _INT1Interrupt(void)
{
	IFS1bits.INT1IF = 0; // clear flag

	unsigned int pa = (PORTA & 0x000F); // get port values
	unsigned int pb = ((PORTB & 0x003C) << 2);
	
	term_last_channel = 0x0000; // indicate channel use
	term_last_address += 2; // increment channel address
	
	term_array[term_last_address] = (pb | pa); // store in array
}

void __attribute__((interrupt, auto_psv, address(0x010500))) _DMA0Interrupt(void)
{	
	IFS0bits.DMA0IF = 0; // clear flag
};

const __prog__ char __attribute__((space(prog), section("usercode"))) game_pieces[4*4*4*7] = {
	// I
	' ','0',' ',' ',
	' ','0',' ',' ',
	' ','0',' ',' ',
	' ','0',' ',' ',

	' ',' ',' ',' ',
	'0','0','0','0',
	' ',' ',' ',' ',
	' ',' ',' ',' ',

	' ','0',' ',' ',
	' ','0',' ',' ',
	' ','0',' ',' ',
	' ','0',' ',' ',

	' ',' ',' ',' ',
	'0','0','0','0',
	' ',' ',' ',' ',
	' ',' ',' ',' ',

	// J
	' ',' ','0',' ',
	' ',' ','0',' ',
	' ','0','0',' ',
	' ',' ',' ',' ',

	' ',' ',' ',' ',
	'0','0','0',' ',
	' ',' ','0',' ',
	' ',' ',' ',' ',

	' ',' ',' ',' ',
	' ','0','0',' ',
	' ','0',' ',' ',
	' ','0',' ',' ',

	' ',' ',' ',' ',
	' ','0',' ',' ',
	' ','0','0','0',
	' ',' ',' ',' ',

	// L
	' ','0',' ',' ',
	' ','0',' ',' ',
	' ','0','0',' ',
	' ',' ',' ',' ',

	' ',' ',' ',' ',
	' ',' ','0',' ',
	'0','0','0',' ',
	' ',' ',' ',' ',

	' ',' ',' ',' ',
	' ','0','0',' ',
	' ',' ','0',' ',
	' ',' ','0',' ',

	' ',' ',' ',' ',
	' ','0','0','0',
	' ','0',' ',' ',
	' ',' ',' ',' ',

	// O
	' ','0','0',' ',
	' ','0','0',' ',
	' ',' ',' ',' ',
	' ',' ',' ',' ',

	' ','0','0',' ',
	' ','0','0',' ',
	' ',' ',' ',' ',
	' ',' ',' ',' ',

	' ','0','0',' ',
	' ','0','0',' ',
	' ',' ',' ',' ',
	' ',' ',' ',' ',

	' ','0','0',' ',
	' ','0','0',' ',
	' ',' ',' ',' ',
	' ',' ',' ',' ',

	// S
	' ',' ',' ',' ',
	' ','0','0',' ',
	'0','0',' ',' ',
	' ',' ',' ',' ',

	' ','0',' ',' ',
	' ','0','0',' ',
	' ',' ','0',' ',
	' ',' ',' ',' ',

	' ',' ',' ',' ',
	' ','0','0',' ',
	'0','0',' ',' ',
	' ',' ',' ',' ',

	' ','0',' ',' ',
	' ','0','0',' ',
	' ',' ','0',' ',
	' ',' ',' ',' ',

	// Z
	' ',' ',' ',' ',
	'0','0',' ',' ',
	' ','0','0',' ',
	' ',' ',' ',' ',

	' ',' ','0',' ',
	' ','0','0',' ',
	' ','0',' ',' ',
	' ',' ',' ',' ',

	' ',' ',' ',' ',
	'0','0',' ',' ',
	' ','0','0',' ',
	' ',' ',' ',' ',

	' ',' ','0',' ',
	' ','0','0',' ',
	' ','0',' ',' ',
	' ',' ',' ',' ',

	// T
	' ','0',' ',' ',
	'0','0','0',' ',
	' ',' ',' ',' ',
	' ',' ',' ',' ',

	' ','0',' ',' ',
	'0','0',' ',' ',
	' ','0',' ',' ',
	' ',' ',' ',' ',

	' ',' ',' ',' ',
	'0','0','0',' ',
	' ','0',' ',' ',
	' ',' ',' ',' ',

	' ','0',' ',' ',
	' ','0','0',' ',
	' ','0',' ',' ',
	' ',' ',' ',' ',
};

const __prog__ char __attribute__((space(prog), section("usercode"))) game_bags[7*16] = {
	0, 1, 2, 3, 4, 5, 6,
	6, 4, 3, 5, 0, 1, 2,
	3, 4, 1, 0, 6, 5, 2,
	1, 0, 6, 3, 4, 2, 5,

	5, 2, 1, 3, 4, 0, 6,
	0, 2, 1, 6, 3, 5, 4,
	5, 4, 6, 0, 3, 1, 2,
	4, 5, 2, 6, 1, 0, 3,

	4, 2, 0, 1, 6, 3, 5,
	3, 0, 6, 2, 1, 4, 5,
	1, 0, 3, 4, 5, 6, 2,
	2, 0, 4, 5, 1, 6, 3,

	6, 4, 0, 5, 2, 1, 3,
	1, 2, 4, 5, 6, 3, 0,
	6, 2, 1, 3, 0, 5, 4,
	4, 1, 2, 3, 0, 6, 5,
};
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
